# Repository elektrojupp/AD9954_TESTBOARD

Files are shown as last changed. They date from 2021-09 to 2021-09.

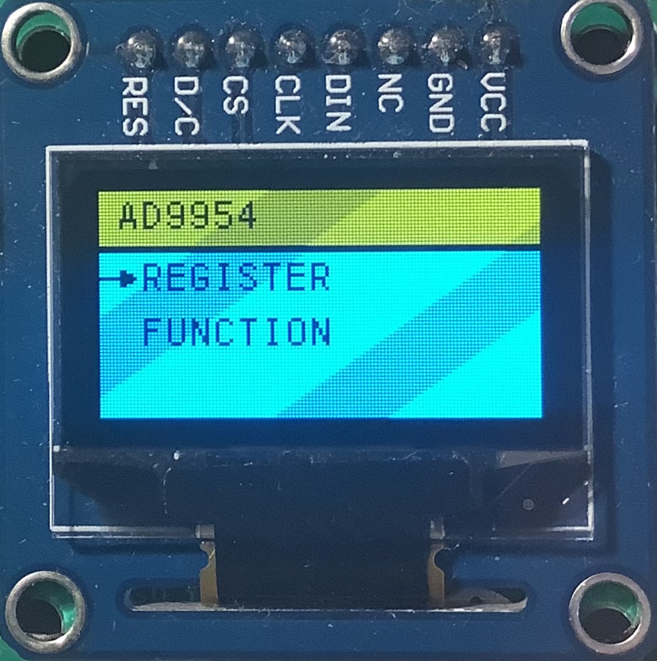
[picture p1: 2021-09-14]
pictures/IMG_E0606.JPG

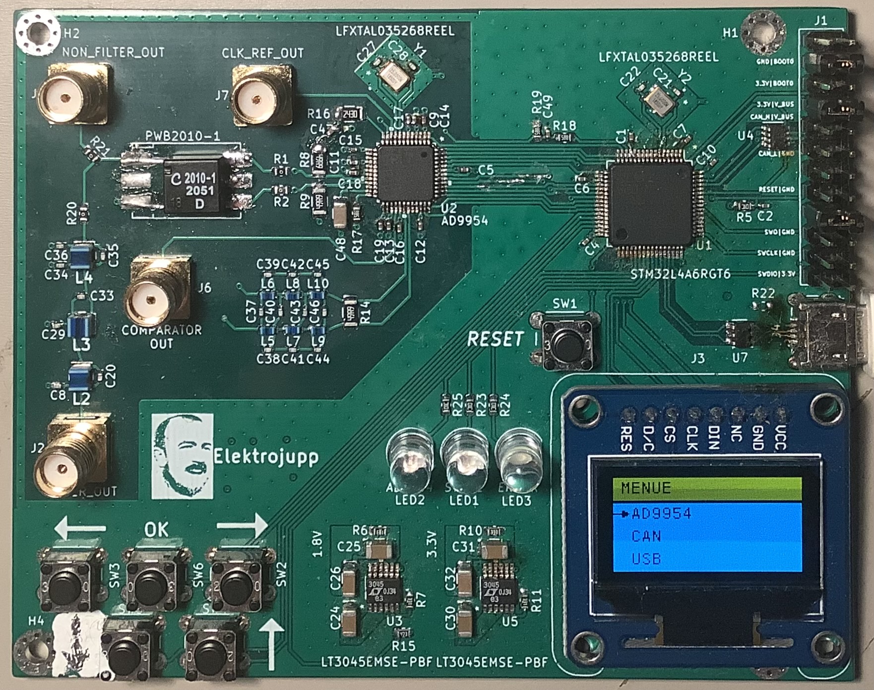
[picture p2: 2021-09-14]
pictures/IMG_E0632.JPG

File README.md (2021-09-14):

# AD9954_TESTBOARD
Testboard for AD9954 controlled by a STM32L4. Available interfaces: SWD, CAN, USB and GUI

# Hardware
Hardware folder contains PCB in as Kicad project.
All used components/footprints/3D models in project specific libary, so it should be possible to open without problems.

# Software
Software folder contains a STM32CubeIDE project. 
For compilation it might be necessary to have the STM32L4 support package installed.
All interfaces are accessible via software:
AD9954 can run in single tone mode,
USB runs as loopserver, CAN interface initiates (no further testing).
GUI menue structure is a bit blown up but flexible. 
STM32L4 runs FREERTOS RTO. Every interface has its own task. 
Communication over queues and semaphores, between different tasks,
so its possible to implement communication over USB/CAN to AD9954.
When a button is pressed during RESET, a snake game appears. 
Speacial feature of the snake game is to store the highscore in flash (simple eeprom emulation).

# Frontview PCB 
More Pictures in Picture folder
IMG_E0632

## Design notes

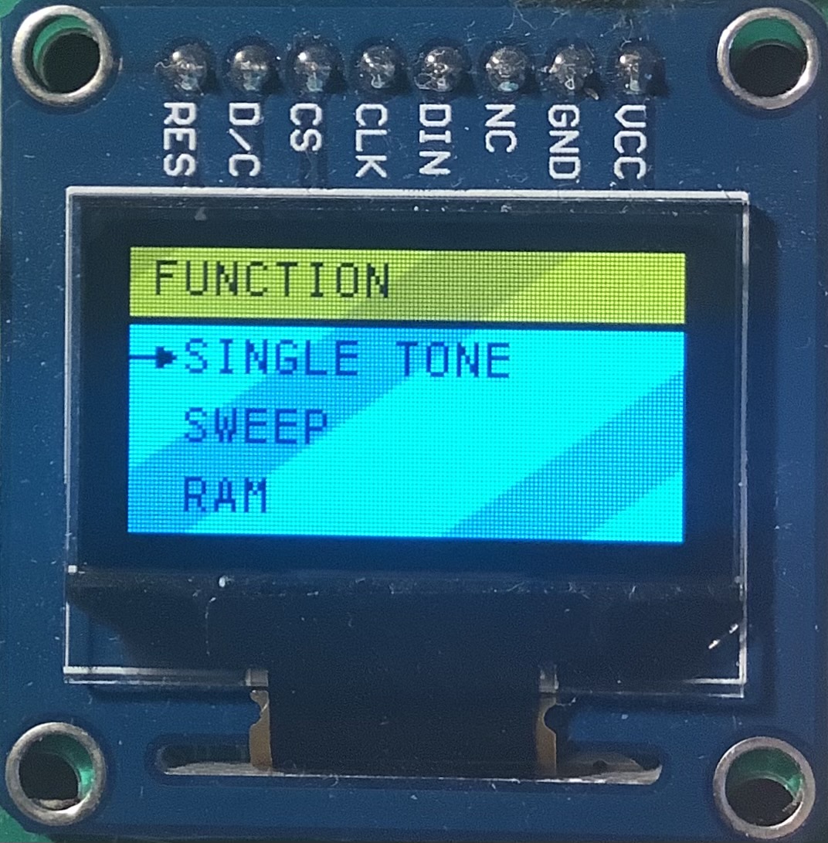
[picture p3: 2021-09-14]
pictures/IMG_E0607.JPG

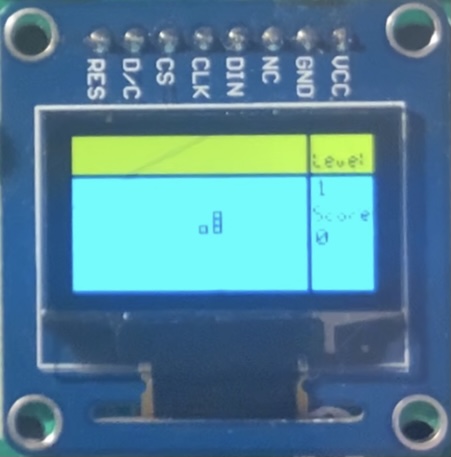
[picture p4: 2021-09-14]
pictures/IMG_E0615.JPG

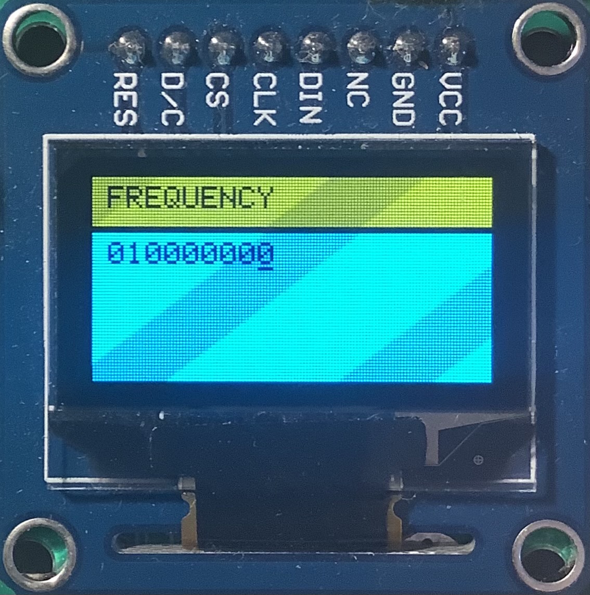
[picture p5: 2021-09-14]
pictures/IMG_E0609.JPG

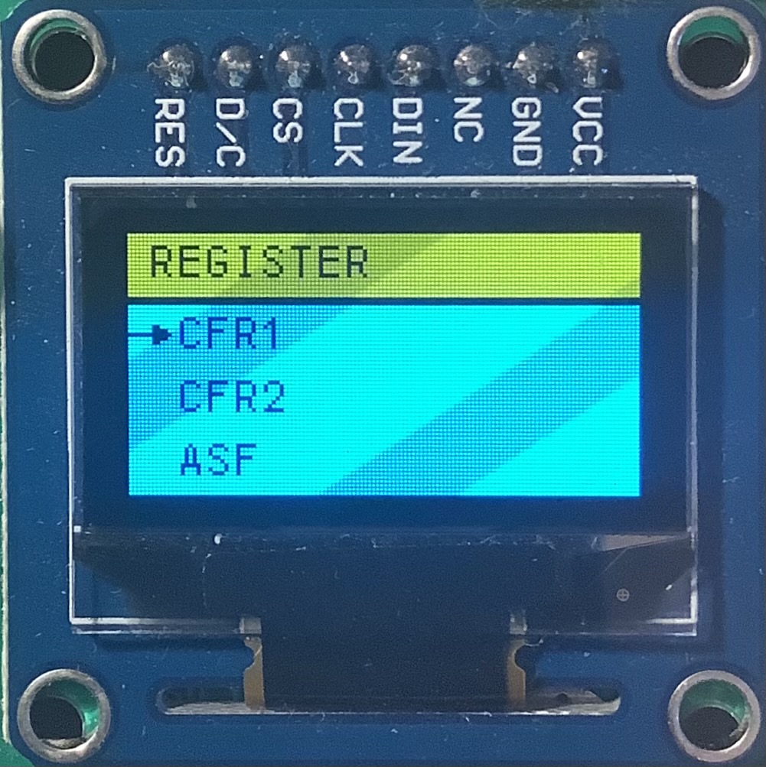
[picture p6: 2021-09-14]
pictures/IMG_E0611.JPG

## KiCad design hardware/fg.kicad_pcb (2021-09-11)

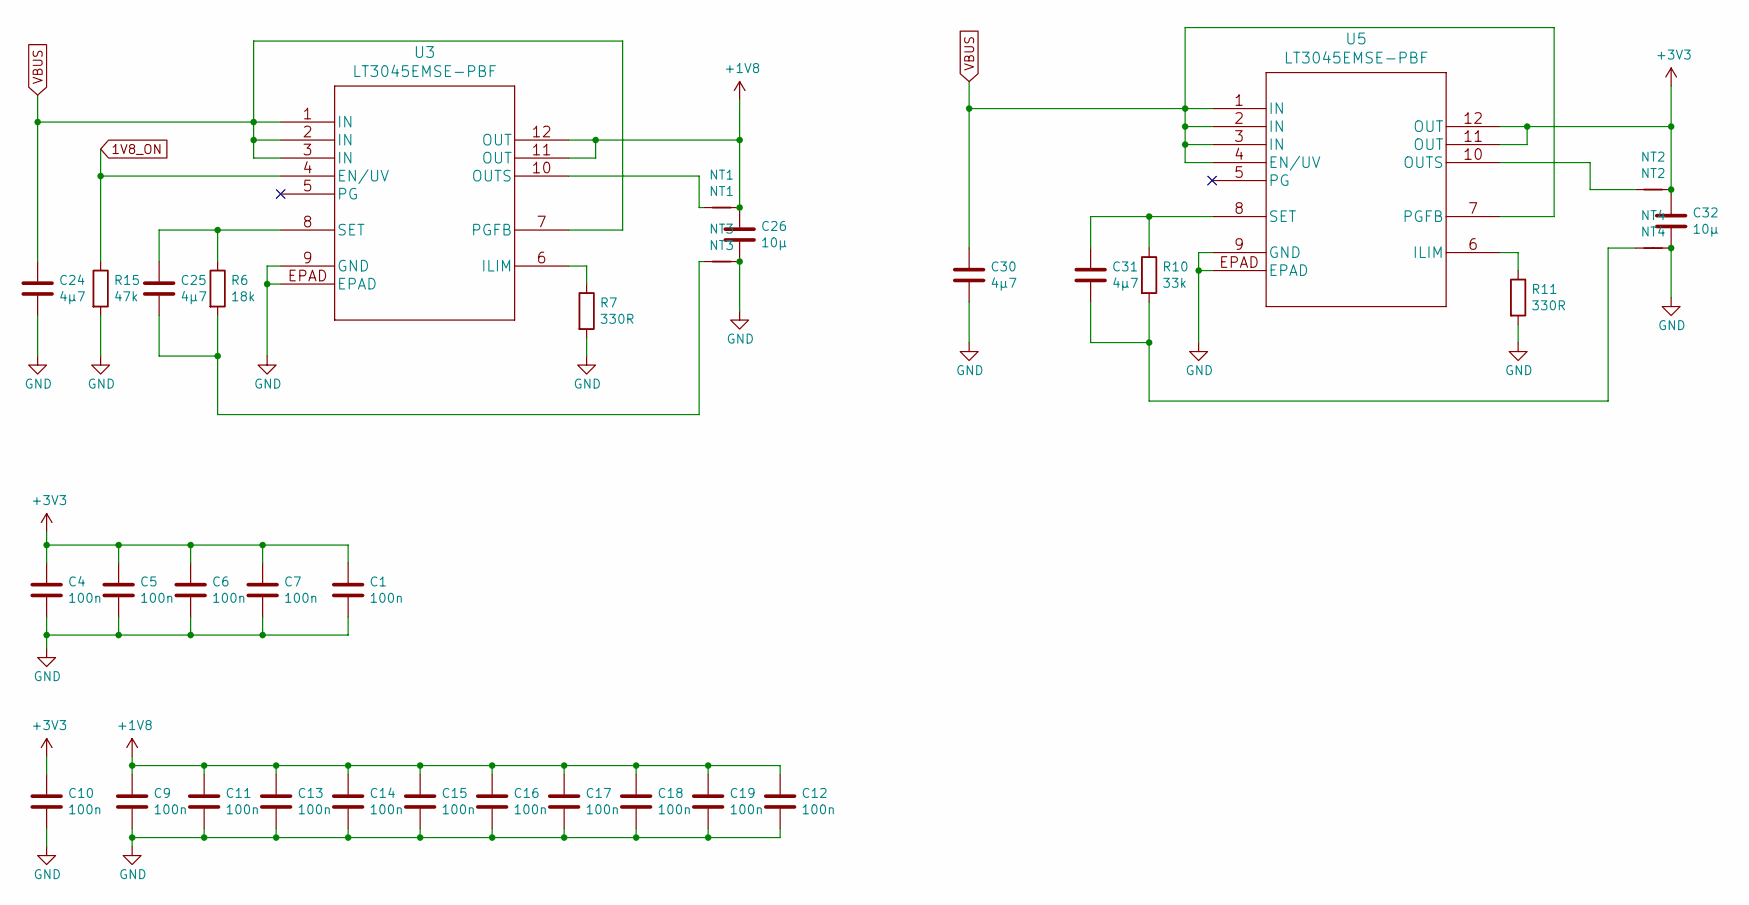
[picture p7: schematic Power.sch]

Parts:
C1, C4, C5, C6, C7, C9, C10, C11, C12, C13, C14, C15, C16, C17, C18, C19: 100n; C_0402_1005Metric
C24, C25, C30, C31: 4µ7; C_1206_3216Metric
C26, C32: 10µ; C_1206_3216Metric
NT1: NT1; NetTie-2_SMD_Pad0.5mm
NT2: NT2; NetTie-2_SMD_Pad0.5mm
NT3: NT3; NetTie-2_SMD_Pad1.0mm
NT4: NT4; NetTie-2_SMD_Pad1.0mm
R6: 18k; R_0603_1608Metric
R7, R11: 330R; R_0603_1608Metric
R10: 33k; R_0603_1608Metric
R15: 47k; R_0603_1608Metric
U3, U5: LT3045EMSE-PBF

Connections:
1V8_ON: R15.1, U3.4 (EN/UV); also elsewhere on the board
+1V8: C9.1, C11.1, C12.1, C13.1, C14.1, C15.1, C16.1, C17.1, C18.1, C19.1, C26.1, NT1.2, U3.11 (OUT), U3.12 (OUT); also elsewhere on the board
+3V3: C1.1, C4.1, C5.1, C6.1, C7.1, C10.1, C32.1, NT2.2, U5.11 (OUT), U5.12 (OUT); also elsewhere on the board
GND: C1.2, C4.2, C5.2, C6.2, C7.2, C9.2, C10.2, C11.2, C12.2, C13.2, C14.2, C15.2, C16.2, C17.2, C18.2, C19.2, C24.2, C26.2, C30.2, C32.2, NT3.2, NT4.2, R7.2, R11.2, R15.2, U3.9 (GND), U3.EPAD, U5.9 (GND), U5.EPAD; also elsewhere on the board
unnamed: C25.1, R6.1, U3.8 (SET)
unnamed: C25.2, NT3.1, R6.2
unnamed: C31.1, R10.1, U5.8 (SET)
unnamed: C31.2, NT4.1, R10.2
unnamed: NT1.1, U3.10 (OUTS)
unnamed: NT2.1, U5.10 (OUTS)
unnamed: R7.1, U3.6 (ILIM)
unnamed: R11.1, U5.6 (ILIM)
VBUS: C24.1, C30.1, U3.1 (IN), U3.2 (IN), U3.3 (IN), U3.7 (PGFB), U5.1 (IN), U5.2 (IN), U5.3 (IN), U5.4 (EN/UV), U5.7 (PGFB); also elsewhere on the board

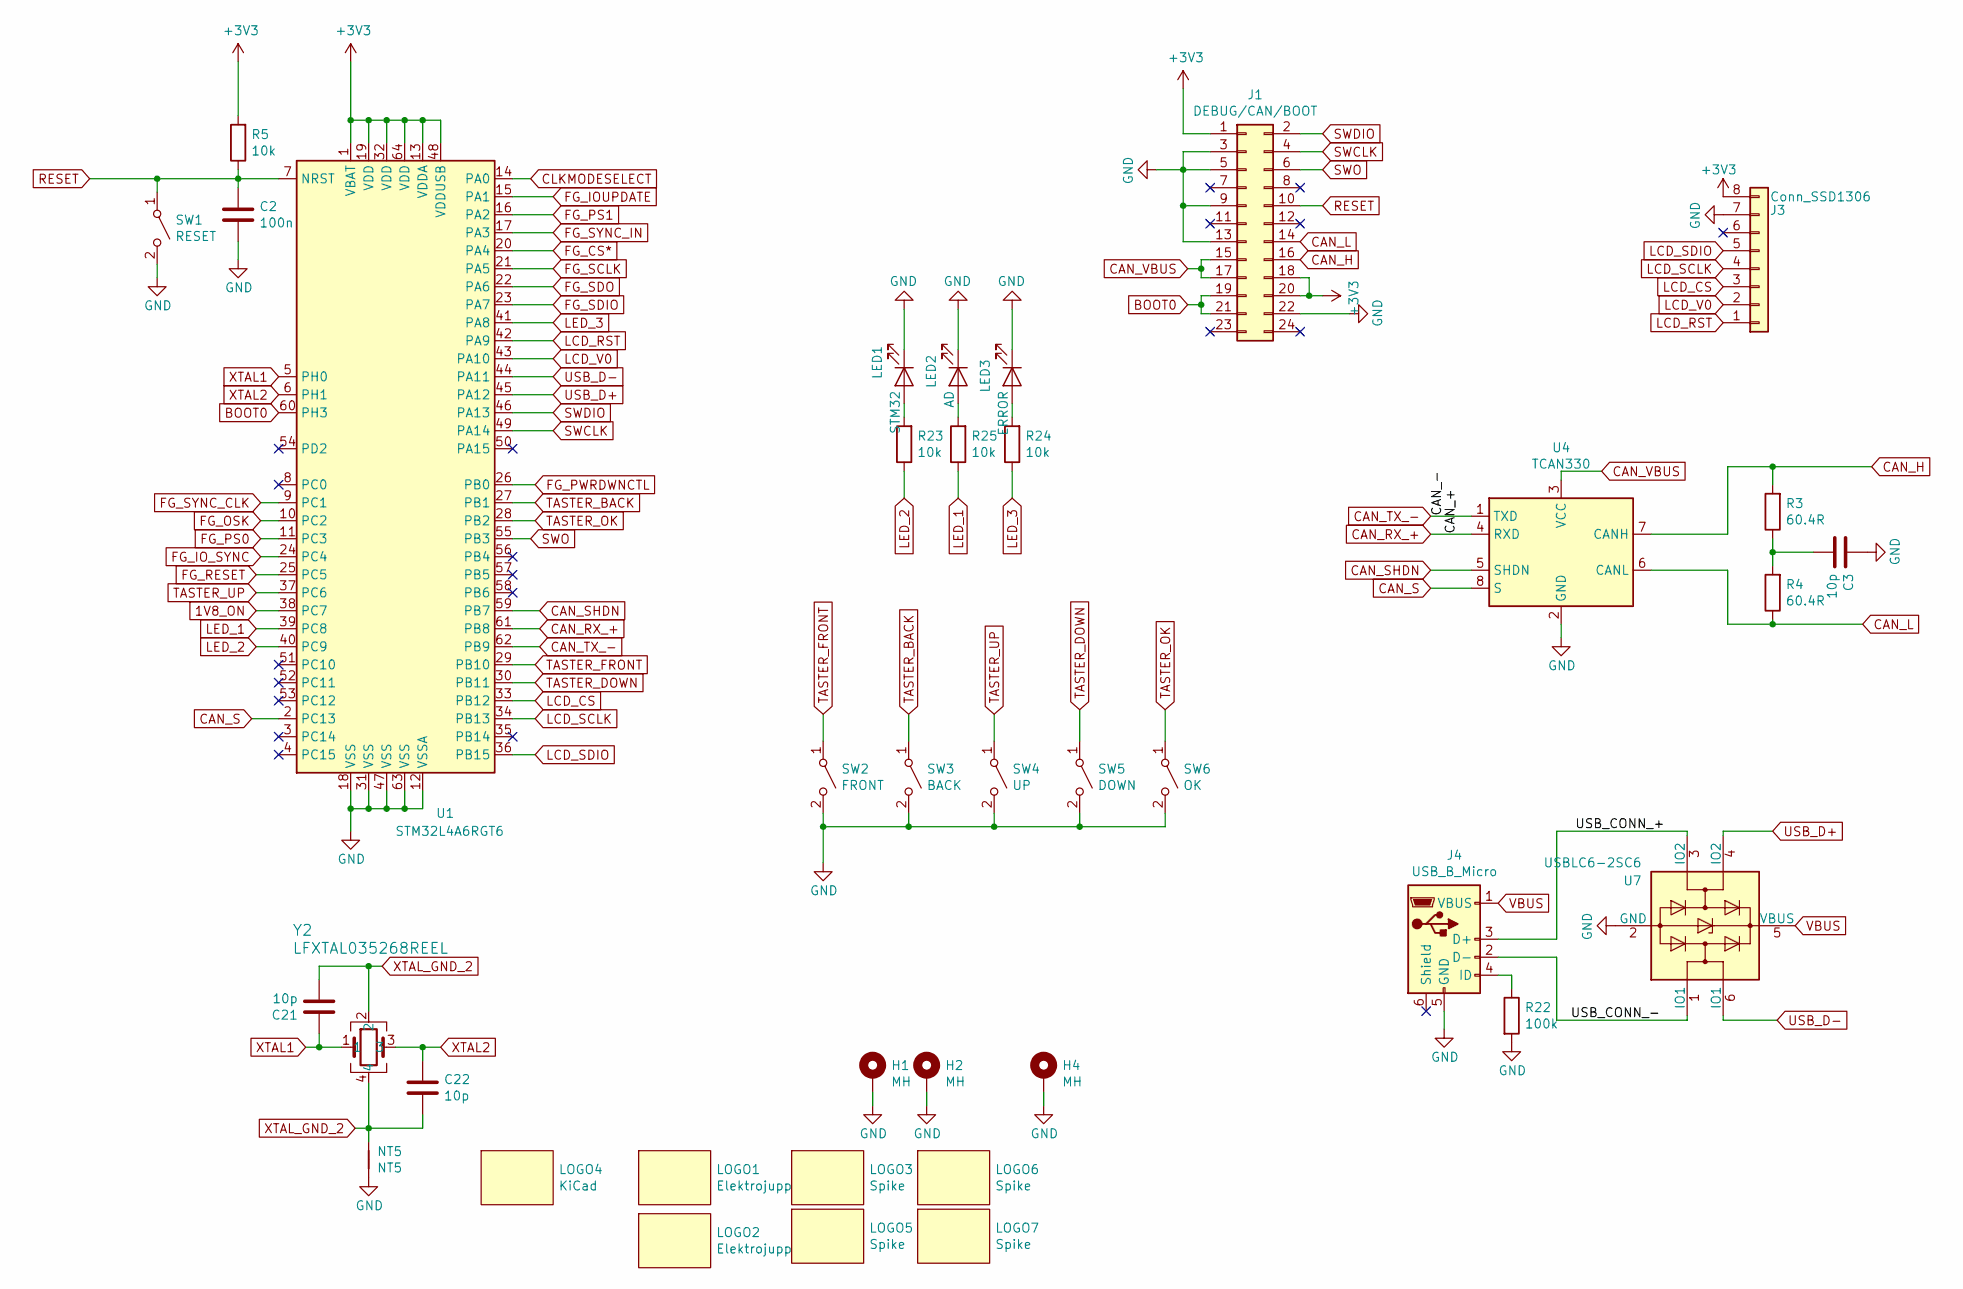
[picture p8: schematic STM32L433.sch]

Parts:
C2: 100n; C_0402_1005Metric
C3, C21, C22: 10p; C_0402_1005Metric
H1, H2, H4: MH; MountingHole_2.7mm_M2.5_Pad_Via
J1: DEBUG/CAN/BOOT; PinHeader_2x12_P2.54mm_Vertical
J3: Conn_SSD1306; Adafruit_SSD1306
J4: USB_B_Micro; USB_Micro-B_Wuerth_629105150521
LED1: STM32; LED_D5.0mm
LED2: AD; LED_D5.0mm
LED3: ERROR; LED_D5.0mm
LOGO1, LOGO2: Elektrojupp; Logo_Elektrojupp
LOGO3, LOGO5, LOGO6, LOGO7: Spike
LOGO4: KiCad; KiCad-Logo2_12mm_SilkScreen
NT5: NT5; NetTie-2_SMD_Pad0.5mm
R3, R4: 60.4R; R_1206_3216Metric
R5, R23, R24, R25: 10k; R_0603_1608Metric
R22: 100k; R_0603_1608Metric
SW1: RESET; SW_PUSH_6mm_H5mm
SW2: FRONT; SW_PUSH_6mm_H5mm
SW3: BACK; SW_PUSH_6mm_H5mm
SW4: UP; SW_PUSH_6mm_H5mm
SW5: DOWN; SW_PUSH_6mm_H5mm
SW6: OK; SW_PUSH_6mm_H5mm
U1: STM32L4A6RGT6; LQFP-64_10x10mm_P0.5mm
U4: TCAN330; SOT-23-8
U7: USBLC6-2SC6; SOT-23-6
Y2: LFXTAL035268REEL; CFPX-180

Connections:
1V8_ON: U1.38 (PC7); also elsewhere on the board
+3V3: J1.1, J1.18, J1.20, J3.8, R5.2, U1.1 (VBAT), U1.13 (VDDA), U1.19 (VDD), U1.32 (VDD), U1.48 (VDDUSB), U1.64 (VDD); also elsewhere on the board
/STM32L433/USB_CONN_+: J4.3 (D+), U7.3 (IO2)
/STM32L433/USB_CONN_-: J4.2 (D-), U7.1 (IO1)
BOOT0: J1.19, J1.21, U1.60 (PH3)
CAN_H: J1.16, R3.2, U4.7 (CANH)
CAN_L: J1.14, R4.1, U4.6 (CANL)
CAN_RX_+: U1.61 (PB8), U4.4 (RXD)
CAN_S: U1.2 (PC13), U4.8 (S)
CAN_SHDN: U1.59 (PB7), U4.5 (SHDN)
CAN_TX_-: U1.62 (PB9), U4.1 (TXD)
CAN_VBUS: J1.15, J1.17, U4.3 (VCC)
CLKMODESELECT: U1.14 (PA0); also elsewhere on the board
FG_CS*: U1.20 (PA4); also elsewhere on the board
FG_IOUPDATE: U1.15 (PA1); also elsewhere on the board
FG_IO_SYNC: U1.24 (PC4); also elsewhere on the board
FG_OSK: U1.10 (PC2); also elsewhere on the board
FG_PS0: U1.11 (PC3); also elsewhere on the board
FG_PS1: U1.16 (PA2); also elsewhere on the board
FG_PWRDWNCTL: U1.26 (PB0); also elsewhere on the board
FG_RESET: U1.25 (PC5); also elsewhere on the board
FG_SCLK: U1.21 (PA5); also elsewhere on the board
FG_SDIO: U1.23 (PA7); also elsewhere on the board
FG_SDO: U1.22 (PA6); also elsewhere on the board
FG_SYNC_CLK: U1.9 (PC1); also elsewhere on the board
FG_SYNC_IN: U1.17 (PA3); also elsewhere on the board
GND: C2.2, C3.1, H1.1, H2.1, H4.1, J1.3, J1.5, J1.9, J1.13, J1.22, J3.7, J4.5 (GND), LED1.1 (K), LED2.1 (K), LED3.1 (K), NT5.1, R22.2, SW1.2 (B), SW2.2 (B), SW3.2 (B), SW4.2 (B), SW5.2 (B), SW6.2 (B), U1.12 (VSSA), U1.18 (VSS), U1.31 (VSS), U1.47 (VSS), U1.63 (VSS), U4.2 (GND), U7.2 (GND); also elsewhere on the board
LCD_CS: J3.3, U1.33 (PB12)
LCD_RST: J3.1, U1.42 (PA9)
LCD_SCLK: J3.4, U1.34 (PB13)
LCD_SDIO: J3.5, U1.36 (PB15)
LCD_V0: J3.2, U1.43 (PA10)
LED_1: R25.1, U1.39 (PC8)
LED_2: R23.1, U1.40 (PC9)
LED_3: R24.1, U1.41 (PA8)
unnamed: C3.2, R3.1, R4.2
unnamed: J4.4 (ID), R22.1
unnamed: LED1.2 (A), R23.2
unnamed: LED2.2 (A), R25.2
unnamed: LED3.2 (A), R24.2
RESET: C2.1, J1.10, R5.1, SW1.1 (A), U1.7 (NRST)
SWCLK: J1.4, U1.49 (PA14)
SWDIO: J1.2, U1.46 (PA13)
SWO: J1.6, U1.55 (PB3)
TASTER_BACK: SW3.1 (A), U1.27 (PB1)
TASTER_DOWN: SW5.1 (A), U1.30 (PB11)
TASTER_FRONT: SW2.1 (A), U1.29 (PB10)
TASTER_OK: SW6.1 (A), U1.28 (PB2)
TASTER_UP: SW4.1 (A), U1.37 (PC6)
USB_D+: U1.45 (PA12), U7.4 (IO2)
USB_D-: U1.44 (PA11), U7.6 (IO1)
VBUS: J4.1 (VBUS), U7.5 (VBUS); also elsewhere on the board
XTAL1: C21.1, U1.5 (PH0), Y2.1
XTAL2: C22.1, U1.6 (PH1), Y2.3
XTAL_GND_2: C21.2, C22.2, NT5.2, Y2.2, Y2.4

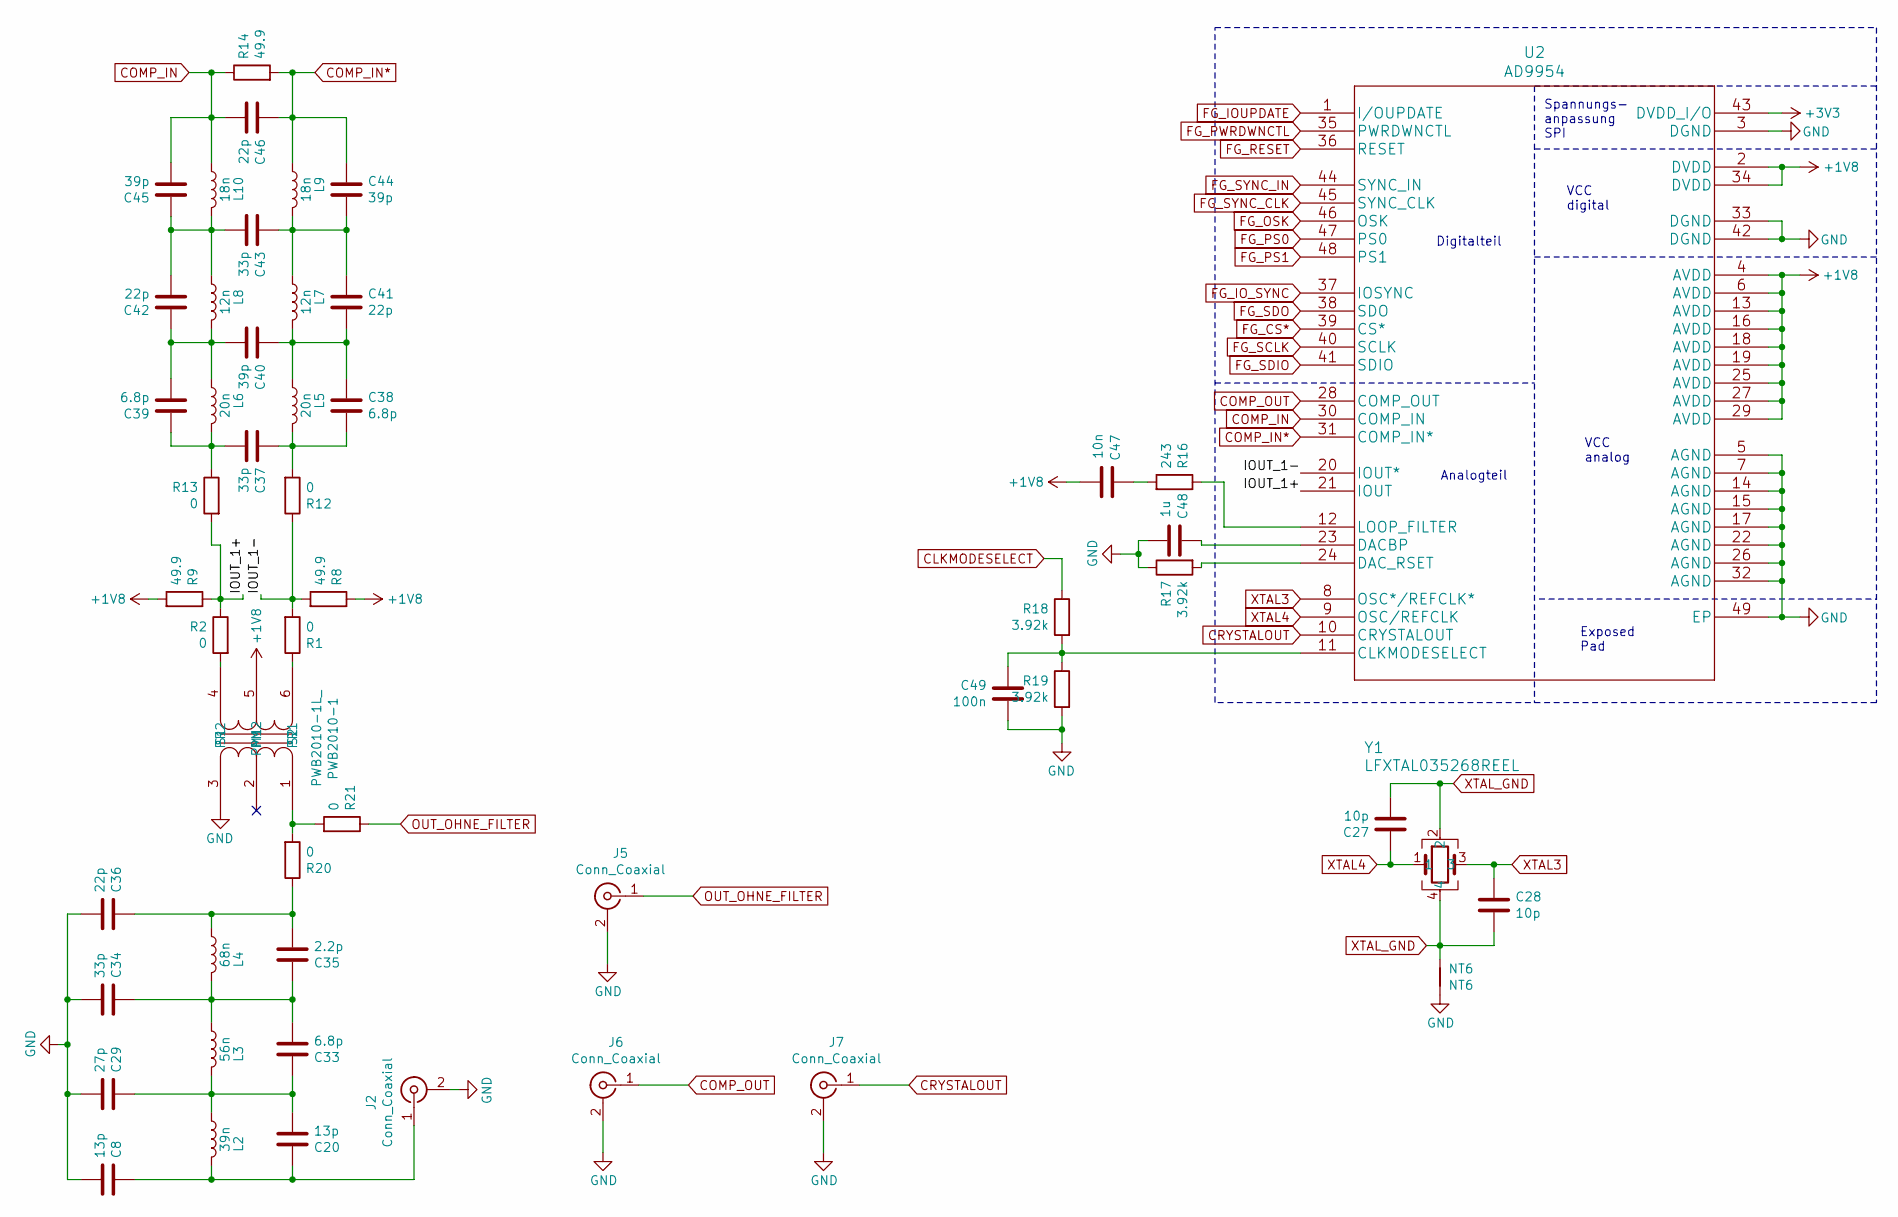
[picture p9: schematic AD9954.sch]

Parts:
C8, C20: 13p; C_0402_1005Metric
C27, C28: 10p; C_0402_1005Metric
C29: 27p; C_0402_1005Metric
C33, C38, C39: 6.8p; C_0402_1005Metric
C34, C37, C43: 33p; C_0402_1005Metric
C35: 2.2p; C_0402_1005Metric
C36, C41, C42, C46: 22p; C_0402_1005Metric
C40, C44, C45: 39p; C_0402_1005Metric
C47: 10n; C_0402_1005Metric
C48: 1u; C_1206_3216Metric
C49: 100n; C_0402_1005Metric
J2, J5, J6, J7: Conn_Coaxial; SMA_Amphenol_132291_Vertical
L2: 39n; 1008HQ39NXGLB
L3: 56n; 1008HQ39NXGLB
L4: 68n; 1008HQ39NXGLB
L5, L6: 20n; L_0603_1608Metric
L7, L8: 12n; L_0603_1608Metric
L9, L10: 18n; L_0603_1608Metric
NT6: NT6; NetTie-2_SMD_Pad0.5mm
PWB2010-1: PWB2010-1L_; Transformer_NF_ETAL
R1, R2, R12, R13, R20, R21: 0; R_0603_1608Metric
R8, R9, R14: 49.9; R_1206_3216Metric
R16: 243; R_1206_3216Metric
R17, R18, R19: 3.92k; R_0603_1608Metric
U2: AD9954
Y1: LFXTAL035268REEL; CFPX-180

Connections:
+1V8: C47.2, PWB2010-1.5 (PM1), R8.1, R9.2, U2.2 (DVDD), U2.4 (AVDD), U2.6 (AVDD), U2.13 (AVDD), U2.16 (AVDD), U2.18 (AVDD), U2.19 (AVDD), U2.25 (AVDD), U2.27 (AVDD), U2.29 (AVDD), U2.34 (DVDD); also elsewhere on the board
+3V3: U2.43 (DVDD_I/O); also elsewhere on the board
/AD9954/IOUT_1+: R2.1, R9.1, R13.2, U2.21 (IOUT)
/AD9954/IOUT_1-: R1.2, R8.2, R12.1, U2.20 (IOUT*)
CLKMODESELECT: R18.1; also elsewhere on the board
COMP_IN: C45.2, C46.2, L10.1, R14.1, U2.30 (COMP_IN)
COMP_IN*: C44.1, C46.1, L9.1, R14.2, U2.31 (COMP_IN*)
COMP_OUT: J6.1 (In), U2.28 (COMP_OUT)
CRYSTALOUT: J7.1 (In), U2.10 (CRYSTALOUT)
FG_CS*: U2.39 (CS*); also elsewhere on the board
FG_IOUPDATE: U2.1 (I/OUPDATE); also elsewhere on the board
FG_IO_SYNC: U2.37 (IOSYNC); also elsewhere on the board
FG_OSK: U2.46 (OSK); also elsewhere on the board
FG_PS0: U2.47 (PS0); also elsewhere on the board
FG_PS1: U2.48 (PS1); also elsewhere on the board
FG_PWRDWNCTL: U2.35 (PWRDWNCTL); also elsewhere on the board
FG_RESET: U2.36 (RESET); also elsewhere on the board
FG_SCLK: U2.40 (SCLK); also elsewhere on the board
FG_SDIO: U2.41 (SDIO); also elsewhere on the board
FG_SDO: U2.38 (SDO); also elsewhere on the board
FG_SYNC_CLK: U2.45 (SYNC_CLK); also elsewhere on the board
FG_SYNC_IN: U2.44 (SYNC_IN); also elsewhere on the board
GND: C8.2, C29.2, C34.2, C36.2, C48.2, C49.2, J2.2 (Ext), J5.2 (Ext), J6.2 (Ext), J7.2 (Ext), NT6.1, PWB2010-1.3 (PR2), R17.1, R19.2, U2.3 (DGND), U2.5 (AGND), U2.7 (AGND), U2.14 (AGND), U2.15 (AGND), U2.17 (AGND), U2.22 (AGND), U2.26 (AGND), U2.32 (AGND), U2.33 (DGND), U2.42 (DGND), U2.49 (EP); also elsewhere on the board
unnamed: C8.1, C20.1, J2.1 (In), L2.1
unnamed: C20.2, C29.1, C33.1, L2.2, L3.1
unnamed: C33.2, C34.1, C35.1, L3.2, L4.1
unnamed: C35.2, C36.1, L4.2, R20.1
unnamed: C37.1, C38.2, L5.2, R12.2
unnamed: C37.2, C39.1, L6.2, R13.1
unnamed: C38.1, C40.1, C41.2, L5.1, L7.2
unnamed: C39.2, C40.2, C42.1, L6.1, L8.2
unnamed: C41.1, C43.1, C44.2, L7.1, L9.2
unnamed: C42.2, C43.2, C45.1, L8.1, L10.2
unnamed: C47.1, R16.2
unnamed: C48.1, U2.23 (DACBP)
unnamed: C49.1, R18.2, R19.1, U2.11 (CLKMODESELECT)
unnamed: PWB2010-1.1 (PR1), R20.2, R21.2
unnamed: PWB2010-1.4 (S1), R2.2
unnamed: PWB2010-1.6 (S2), R1.1
unnamed: R16.1, U2.12 (LOOP_FILTER)
unnamed: R17.2, U2.24 (DAC_RSET)
OUT_OHNE_FILTER: J5.1 (In), R21.1
XTAL3: C28.1, U2.8 (OSC*/REFCLK*), Y1.3
XTAL4: C27.1, U2.9 (OSC/REFCLK), Y1.1
XTAL_GND: C27.2, C28.2, NT6.2, Y1.2, Y1.4

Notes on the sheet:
Analogteil
Digitalteil
Spannungs- anpassung SPI
VCC digital
VCC analog
Exposed Pad

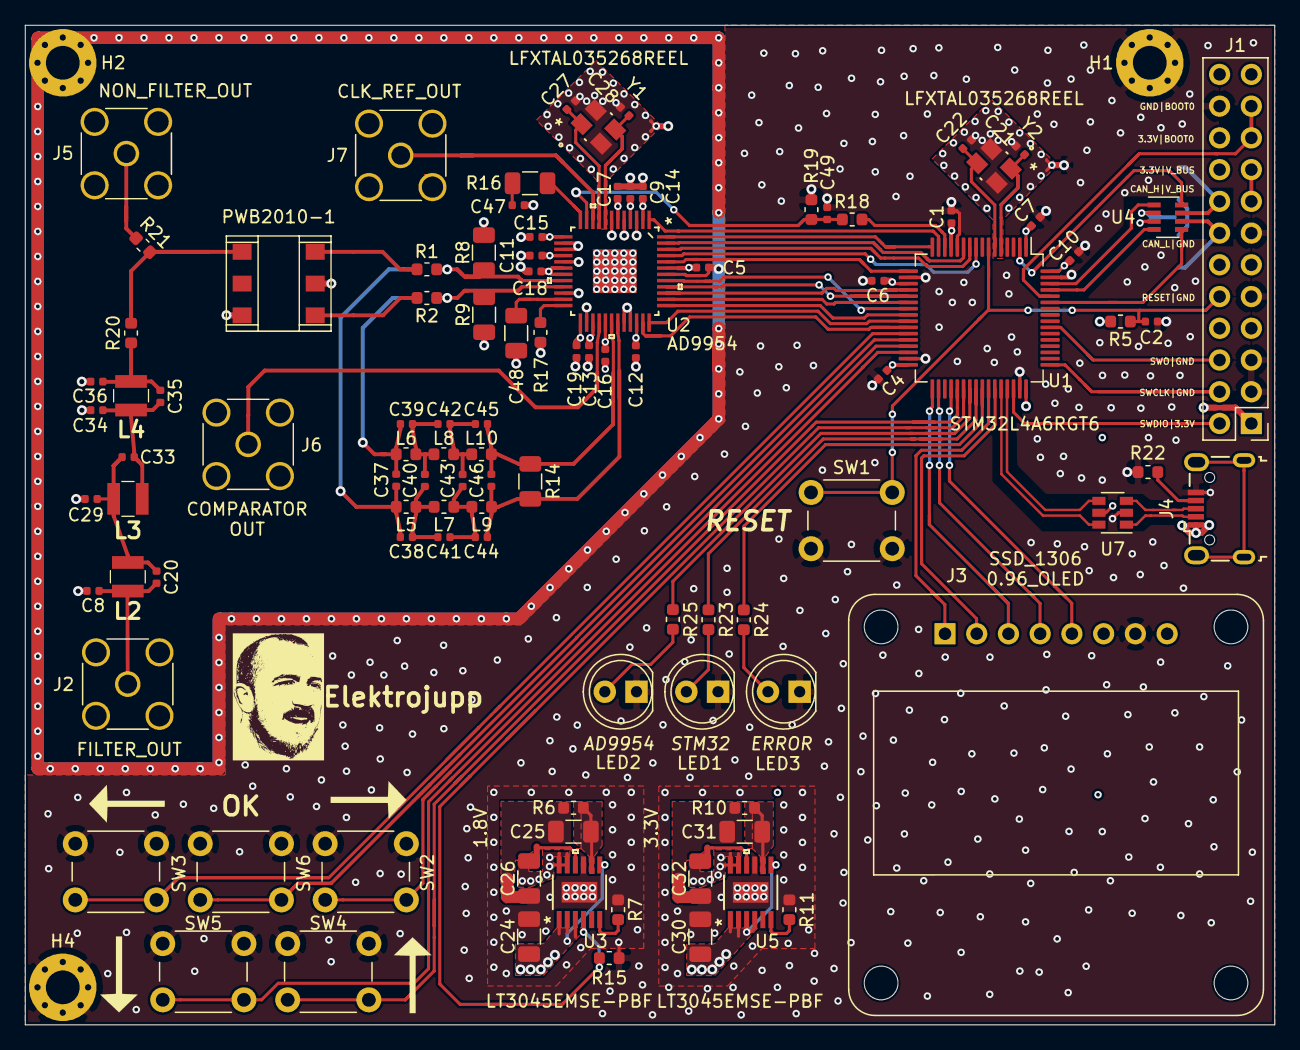
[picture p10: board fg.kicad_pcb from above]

Board: 4 copper layers, 100.0 x 80.0 mm, 123 parts (0 on the bottom side), 92 nets.

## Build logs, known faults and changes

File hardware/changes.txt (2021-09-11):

Schematics:

V2
Rename Spannungsversorgung to Power
VDDUSB (STM32L4, PIN 48) from VBUS to 3V3
PWB2010-1 Footprint change
SSD1306 Footprint change
Remove H3 (mounting hole)

Layout:

V2
LOGO6 (Spike) rotate 180°
STM32 PIN 48 to 3V3 (erase old connection)
few dukos change from 1V8 to GND (they shouldve been GND)
all planes connection from solid to thermal (problems with soldering some tht)
PWB2010-1 new Footprint new 3D new conns
SSD13306 new Footprint new 3D new conns
Remove H3 (mounting hole 3)

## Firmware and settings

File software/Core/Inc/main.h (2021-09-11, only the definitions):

#define CAN_S_Pin GPIO_PIN_13
#define CAN_S_GPIO_Port GPIOC
#define FG_SYNC_CLK_Pin GPIO_PIN_1
#define FG_SYNC_CLK_GPIO_Port GPIOC
#define FG_OSK_Pin GPIO_PIN_2
#define FG_OSK_GPIO_Port GPIOC
#define FG_PSO_Pin GPIO_PIN_3
#define FG_PSO_GPIO_Port GPIOC
#define FG_CLKMODESELECT_Pin GPIO_PIN_0
#define FG_CLKMODESELECT_GPIO_Port GPIOA
#define FG_IOUPDATE_Pin GPIO_PIN_1
#define FG_IOUPDATE_GPIO_Port GPIOA
#define FG_PS1_Pin GPIO_PIN_2
#define FG_PS1_GPIO_Port GPIOA
#define FG_SYNC_IN_Pin GPIO_PIN_3
#define FG_SYNC_IN_GPIO_Port GPIOA
#define FG_SPI_NSS_Pin GPIO_PIN_4
#define FG_SPI_NSS_GPIO_Port GPIOA
#define FG_SPI_SCLK_Pin GPIO_PIN_5
#define FG_SPI_SCLK_GPIO_Port GPIOA
#define FG_SPI_MOSI_Pin GPIO_PIN_7
#define FG_SPI_MOSI_GPIO_Port GPIOA
#define FG_IO_SYNC_Pin GPIO_PIN_4
#define FG_IO_SYNC_GPIO_Port GPIOC
#define FG_RESET_Pin GPIO_PIN_5
#define FG_RESET_GPIO_Port GPIOC
#define FG_PWRDNCTL_Pin GPIO_PIN_0
#define FG_PWRDNCTL_GPIO_Port GPIOB
#define TASTER_BACK_Pin GPIO_PIN_1
#define TASTER_BACK_GPIO_Port GPIOB
#define TASTER_OK_Pin GPIO_PIN_2
#define TASTER_OK_GPIO_Port GPIOB
#define TASTER_FRONT_Pin GPIO_PIN_10
#define TASTER_FRONT_GPIO_Port GPIOB
#define TASTER_DOWN_Pin GPIO_PIN_11
#define TASTER_DOWN_GPIO_Port GPIOB
#define LCD_SOFTWARE_NSS_Pin GPIO_PIN_12
#define LCD_SOFTWARE_NSS_GPIO_Port GPIOB
#define LCD_SPI_SCLK_Pin GPIO_PIN_13
#define LCD_SPI_SCLK_GPIO_Port GPIOB
#define LCD_SPI_MOSI_Pin GPIO_PIN_15
#define LCD_SPI_MOSI_GPIO_Port GPIOB
#define TASTER_UP_Pin GPIO_PIN_6
#define TASTER_UP_GPIO_Port GPIOC
#define SET_1V8_Pin GPIO_PIN_7
#define SET_1V8_GPIO_Port GPIOC
#define LED_AD9954_Pin GPIO_PIN_8
#define LED_AD9954_GPIO_Port GPIOC
#define LED_STM32_Pin GPIO_PIN_9
#define LED_STM32_GPIO_Port GPIOC
#define LED_ERROR_Pin GPIO_PIN_8
#define LED_ERROR_GPIO_Port GPIOA
#define LCD_RST_Pin GPIO_PIN_9
#define LCD_RST_GPIO_Port GPIOA
#define LCD_V0_Pin GPIO_PIN_10
#define LCD_V0_GPIO_Port GPIOA
#define CAN_SHDN_Pin GPIO_PIN_7
#define CAN_SHDN_GPIO_Port GPIOB

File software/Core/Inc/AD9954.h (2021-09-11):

#ifndef __AD9954_H__
#define __AD9954_H__

// includes 
#include "stm32l4xx_hal.h"
#include "cmsis_os.h"

#define AD9954_Delay					osDelay

// AD9954 3V3 logic inputs
#define AD9954_RESET_PIN				GPIO_PIN_5		
#define AD9954_RESET_GPIO_Port 			GPIOC
#define AD9954_OSK_PIN					GPIO_PIN_2
#define AD9954_OSK_GPIO_Port 			GPIOC
#define AD9954_IOUPDATE_PIN				GPIO_PIN_1
#define AD9954_IOUPDATE_GPIO_Port		GPIOA
#define AD9954_PS0_PIN					GPIO_PIN_3
#define AD9954_PS0_GPIO_Port			GPIOC
#define AD9954_PS1_PIN					GPIO_PIN_2				
#define AD9954_PS1_GPIO_Port			GPIOA	
#define AD9954_IOSYNC_PIN				GPIO_PIN_4	
#define AD9954_IOSYNC_GPIO_Port			GPIOC	
#define AD9954_PWRDNCTL_PIN				GPIO_PIN_0
#define AD9954_PWRDNCTL_GPIO_Port		GPIOB	
#define AD9954_SYNCIN_PIN				GPIO_PIN_3
#define AD9954_SYNCIN_GPIO_Port 		GPIOA

// AD9954 1V8 logic input
#define AD9954_CLKMODESELECT_PIN		GPIO_PIN_0
#define AD9954_CLKMODESELECT_GPIO_Port	GPIOA

// AD9954 outputs
#define AD9954_SYNCCLK_Pin 				GPIO_PIN_1
#define AD9954_SYNCCLK_GPIO_Port 		GPIOC


// AD9954 SPI pins
#define AD9954_SPI_HANDLE				hspi1
#define AD9954_SPI_NSS_Pin 				GPIO_PIN_4
#define AD9954_SPI_NSS_GPIO_Port 		GPIOA
#define AD9954_SPI_SCLK_Pin 			GPIO_PIN_5
#define AD9954_SPI_SCLK_GPIO_Port 		GPIOA
#define AD9954_SPI_MISO_Pin 			GPIO_PIN_6
#define AD9954_SPI_MISO_GPIO_Port 		GPIOA
#define AD9954_SPI_MOSI_Pin 			GPIO_PIN_7
#define AD9954_SPI_MOSI_GPIO_Port 		GPIOA



#define AD9954_REFCLOCK					25000000 	//25.000.000 Hz
#define AD9954_CLK_MULTIPLIER			16			// between 4 and 20



// REG address definitions
#define CFR1_REGISTER_ADDRESS			0x00
#define	CFR2_REGISTER_ADDRESS			0x01
#define ASF_REGISTER_ADDRESS			0x02
#define	ARR_REGISTER_ADDRESS			0x03
#define	FTW0_REGISTER_ADDRESS			0x04
#define	POW0_REGISTER_ADDRESS			0x05
#define	FTW1_REGISTER_ADDRESS			0x06
#define	RSCW0_REGISTER_ADDRESS			0x07
#define RSCW1_REGISTER_ADDRESS			0x08
#define RSCW2_REGISTER_ADDRESS			0x09
#define RSCW3_REGISTER_ADDRESS			0x0A
#define	RAM_REGISTER_ADDRESS			0x0B

// in case linear sweep bit is enabled (CFR1 <21> = 1)
#define	NLSCW_REGISTER_ADDRESS			0x07
#define PLSCW_REGISTER_ADDRESS			0x08

/*
#define CRF1_REGISTER_SIZE 				4
#define CRF2_REGISTER_SIZE				3
#define ASF_REGISTER_SIZE				2
#define ARR_REGISTER_SIZE				1
#define FTW0_REGISTER_SIZE				4
#define POW0_REGISTER_SIZE				2
#define FTW1_REGISTER_SIZE				4
#define RSCW0_REGISTER_SIZE				5
#define RSCW1_REGISTER_SIZE				5
#define RSCW3_REGISTER_SIZE				5
#define RSCW4_REGISTER_SIZE				5
#define NLSCW_REGISTER_SIZE				5
#define PLSCW_REGISTER_SIZE				5
*/
//#define	RAM_DATA_SIZE					1024
#define RAM_DATA_SIZE						1024

#define NUMBER_OF_READABLE_REGISTERS		14
#define NUMBER_OF_REGISTERS					14

// CFR1
#define CRF1_REGISTER_SIZE 						4
// BIT 0 not used
// BIT 1
#define CFR1_SYNC_CLK_DISABLE_Pos       		(1U)
#define CFR1_SYNC_CLK_DISABLE_Msk      			(0x1UL << CFR1_SYNC_CLK_DISABLE_Pos)
#define CFR1_SYNC_CLK_DISABLE          			CFR1_SYNC_CLK_DISABLE_Msk
// BIT 2
#define CFR1_LINEAR_SWEEP_NO_DWELL_Pos  		(2U)
#define CFR1_LINEAR_SWEEP_NO_DWELL_Msk  		(0x1UL << CFR1_LINEAR_SWEEP_NO_DWELL_Pos)
#define CFR1_LINEAR_SWEEP_NO_DWELL      		CFR1_LINEAR_SWEEP_NO_DWELL_Msk
// BIT 3
#define CFR1_EXTERNAL_POWER_DOWN_MODE_Pos  		(3U)
#define CFR1_EXTERNAL_POWER_DOWN_MODE_Msk  		(0x1UL << CFR1_EXTERNAL_POWER_DOWN_MODE_Pos)
#define CFR1_EXTERNAL_POWER_DOWN_MODE		    CFR1_EXTERNAL_POWER_DOWN_MODE_Msk
// BIT 4
#define CFR1_CLOCK_INPUT_POWER_DOWN_Pos  		(4U)
#define CFR1_CLOCK_INPUT_POWER_DOWN_Msk  		(0x1UL << CFR1_CLOCK_INPUT_POWER_DOWN_Pos)
#define CFR1_CLOCK_INPUT_POWER_DOWN     		CFR1_CLOCK_INPUT_POWER_DOWN_Msk
// BIT 5
#define CFR1_DAC_POWER_DOWN_Pos  				(5U)
#define CFR1_DAC_POWER_DOWN_Msk  				(0x1UL << CFR1_DAC_POWER_DOWN_Pos)
#define CFR1_DAC_POWER_DOWN     				CFR1_DAC_POWER_DOWN_Msk
// BIT 6
#define CFR1_COMP_POWER_DOWN_Pos  				(6U)
#define CFR1_COMP_POWER_DOWN_Msk  				(0x1UL << CFR1_COMP_POWER_DOWN_Pos)
#define CFR1_COMP_POWER_DOWN     				CFR1_COMP_POWER_DOWN_Msk
// BIT 7
#define CFR1_DIGITAL_POWER_DOWN_Pos  			(7U)
#define CFR1_DIGITAL_POWER_DOWN_Msk  			(0x1UL << CFR1_DIGITAL_POWER_DOWN_Pos)
#define CFR1_DIGITAL_POWER_DOWN     			CFR1_DIGITAL_POWER_DOWN_Msk
// BIT 8
#define CFR1_LSB_FIRST_Pos       				(8U)
#define CFR1_LSB_FIRST_Msk      				(0x1UL << CFR1_LSB_FIRST_Pos)
#define CFR1_LSB_FIRST          				CFR1_LSB_FIRST_Msk
// BIT 9
#define CFR1_SDIO_INPUT_ONLY_Pos  				(9U)
#define CFR1_SDIO_INPUT_ONLY_Msk  				(0x1UL << CFR1_SDIO_INPUT_ONLY_Pos)
#define CFR1_SDIO_INPUT_ONLY      				CFR1_SDIO_INPUT_ONLY_Msk
// BIT 10
#define CFR1_CLEAR_PHASE_ACCUM_Pos  			(10U)
#define CFR1_CLEAR_PHASE_ACCUM_Msk  			(0x1UL << CFR1_CLEAR_PHASE_ACCUM_Pos)
#define CFR1_CLEAR_PHASE_ACCUM		    		CFR1_CLEAR_PHASE_ACCUM_Msk
// BIT 11
#define CFR1_CLEAR_FREQ_ACCUM_Pos  				(11U)
#define CFR1_CLEAR_FREQ_ACCUM_Msk  				(0x1UL << CFR1_CLEAR_FREQ_ACCUM_Pos)
#define CFR1_CLEAR_FREQ_ACCUM		    		CFR1_CLEAR_FREQ_ACCUM_Msk
// BIT 12
#define CFR1_SINE_COSINE_SELECT_Pos  			(12U)
#define CFR1_SINE_COSINE_SELECT_Msk  			(0x1UL << CFR1_SINE_COSINE_SELECT_Pos)
#define CFR1_SINE_COSINE_SELECT		     		CFR1_SINE_COSINE_SELECT_Msk
// BIT 13
#define CFR1_AUTOCLR_PHASE_ACCUM_Pos  			(13U)
#define CFR1_AUTOCLR_PHASE_ACCUM_Msk  			(0x1UL << CFR1_AUTOCLR_PHASE_ACCUM_Pos)
#define CFR1_AUTOCLR_PHASE_ACCUM		    	CFR1_AUTOCLR_PHASE_ACCUM_Msk
// BIT 14
#define CFR1_AUTOCLR_FREQ_ACCUM_Pos  			(14U)
#define CFR1_AUTOCLR_FREQ_ACCUM_Msk  			(0x1UL << CFR1_AUTOCLR_FREQ_ACCUM_Pos)
#define CFR1_AUTOCLR_FREQ_ACCUM		    		CFR1_AUTOCLR_FREQ_ACCUM_Msk
// BIT 15
#define CFR1_SRR_LOAD_ENABLE_Pos  				(15U)
#define CFR1_SRR_LOAD_ENABLE_Msk  				(0x1UL << CFR1_SRR_LOAD_ENABLE_Pos)
#define CFR1_SRR_LOAD_ENABLE    				CFR1_SRR_LOAD_ENABLE_Msk
// BIT 16 - 20 not used
// BIT 21
#define CFR1_LINEAR_SWEEP_ENABLE_Pos  			(21U)
#define CFR1_LINEAR_SWEEP_ENABLE_Msk  			(0x1UL << CFR1_LINEAR_SWEEP_ENABLE_Pos)
#define CFR1_LINEAR_SWEEP_ENABLE   				CFR1_LINEAR_SWEEP_ENABLE_Msk
// BIT 22
#define CFR1_SOFTWARE_MANUAL_SYNC_Pos  			(22U)
#define CFR1_SOFTWARE_MANUAL_SYNC_Msk  			(0x1UL << CFR1_SOFTWARE_MANUAL_SYNC_Pos)
#define CFR1_SOFTWARE_MANUAL_SYNC   			CFR1_SOFTWARE_MANUAL_SYNC_Msk
// BIT 23
#define CFR1_AUTOMATIC_SYNC_ENABLE_Pos  		(23U)
#define CFR1_AUTOMATIC_SYNC_ENABLE_Msk  		(0x1UL << CFR1_AUTOMATIC_SYNC_ENABLE_Pos)
#define CFR1_AUTOMATIC_SYNC_ENABLE    			CFR1_AUTOMATIC_SYNC_ENABLE_Msk
// BIT 24
#define CFR1_AUTO_OSK_ENABLE_Pos  				(24U)
#define CFR1_AUTO_OSK_ENABLE_Msk  				(0x1UL << CFR1_AUTO_OSK_ENABLE_Pos)
#define CFR1_AUTO_OSK_ENABLE    				CFR1_AUTO_OSK_ENABLE_Msk
// BIT 25
#define CFR1_OSK_ENABLE_Pos  					(25U)
#define CFR1_OSK_ENABLE_Msk  					(0x1UL << CFR1_OSK_ENABLE_Pos)
#define CFR1_OSK_ENABLE    						CFR1_OSK_ENABLE_Msk
// BIT 26
#define CFR1_LOAD_ARR_CONTROLL_Pos  			(26U)
#define CFR1_LOAD_ARR_CONTROLL_Msk  			(0x1UL << CFR1_LOAD_ARR_CONTROLL_Pos)
#define CFR1_LOAD_ARR_CONTROLL    				CFR1_LOAD_ARR_CONTROLL_Msk
// BIT 27 - 29
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

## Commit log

2021-09-11 Hardware files in KiCad project
    [AD9954.sch, Power.sch, STM32L433.sch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]
2021-09-11 Kicad project files
    [AD9954.sch, Power.sch, STM32L433.sch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]
2021-09-11 software files STM32CUBE IDE project
    [fg Debug config.cfg]
2021-09-11 add software files
    [fg Debug config.cfg]
2021-09-14 add pictures from PCB and menue structure

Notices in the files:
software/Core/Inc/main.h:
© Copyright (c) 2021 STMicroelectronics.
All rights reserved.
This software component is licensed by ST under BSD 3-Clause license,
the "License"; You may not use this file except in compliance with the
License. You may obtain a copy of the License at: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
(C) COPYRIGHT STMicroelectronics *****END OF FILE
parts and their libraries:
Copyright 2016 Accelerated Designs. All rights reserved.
